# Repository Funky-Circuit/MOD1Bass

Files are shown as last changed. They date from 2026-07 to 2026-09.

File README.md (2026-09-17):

# MOD1Bass
Bass guitar inspired USB and BLE MIDI controller based on an Adafruit Feather ESP32-S3 board
(demo here: https://github.com/user-attachments/assets/1c9dc869-d182-4a1c-bf89-e89e9eab036d)

-- -- --

a bass model was designed for this project. you can find all the files needed in the "MOD1Bass_models" folder and print them or create you own model

-- -- --

all the code for this project was made using the Arduino IDE and the following libraries:
- MiniCore:
https://github.com/mcudude/minicore
- NimBLE:
https://github.com/h2zero/NimBLE-Arduino
- Arduino ESP32:
https://github.com/espressif/arduino-esp32
- Adafruit MAX1704X:
https://github.com/adafruit/Adafruit_MAX1704X
- Adafruit SSD1327:
https://github.com/adafruit/Adafruit_SSD1327
- Adafruit Seesaw:
https://github.com/adafruit/adafruit_seesaw

-- -- --

how to assemble this project:

1. you will need the PCB contained in the "PCB_MOD1Bass_B.json" file (that you can open in the software EasyEDA) with the bottom side preassembled. it will be refered as fretboard.

2. get 4 Atmega328p: for each of them, you will need to burn the bootloader and upload the file "MOD1Bass_fretboard.ino" into them. to do so, you will need an external programmer or an Arduino who is going to act as a programmer thanks to the Arduino IDE example "ArduinoISP". you will need to conect an external 16MHz clock to the Atmega328p and then burn the appropriate bootloader from the minicore board selection.

3. each time you upload the file "MOD1Bass_fretboard.ino" into an Atmega328p after the first, on line 17, you will need to modify the I2C address to 0x12 for the second, 0x13 for the third and 0x14 fo the fourth (for example "Wire.begin(0x12);" for the second) before uploading.

4. once all the Atmega328p are ready, put each of the in on of the four DIP socket on the fretboard (they have a specific order: from left to right, viewed from the top side: 0x11, 0x12, 013, 0x14).

5. connect the fretboard to the screen, the screen to the ANO controller and the ANO controller to the Adafruit Feather ESP32-S3 board with qwiic cables.

6. connect 4 force sensitive resistors (FSRs) to A0, A1, A2 and A3 of the Adafruit Feather ESP32-S3 board, with a 10k pulldown resistor on the signal each. starting from A0 on the left, dispose the FSRs next to each other in the order they where connected (A0, then A1, then A2 and to fnish A3). the other pin of the FSRs needs to be connected to one of the 3V pin of the Adafruit Feather ESP32-S3 board.

7. connect toggle switch (with one pin on the A4 pin and the other pin on the 3V pin) and a li-po battery to the Adafruit Feather ESP32-S3 board (there is a JST 2-PH port made specificaly for power input)

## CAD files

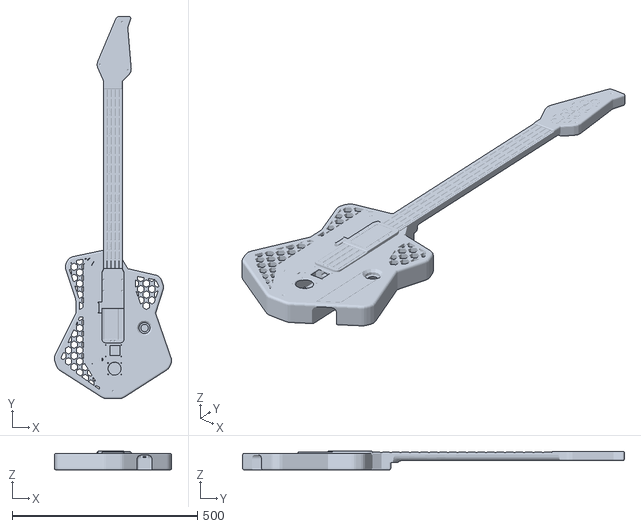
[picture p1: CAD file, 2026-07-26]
MOD1Bass_models/MOD1Bass_full.stl
316.7 x 1030.0 x 51.1

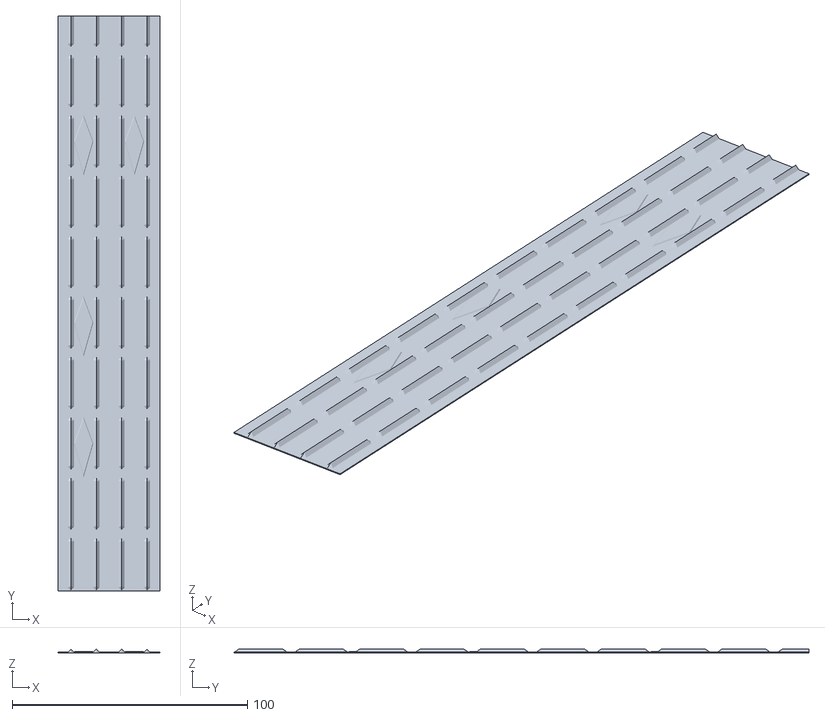
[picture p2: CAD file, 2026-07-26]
MOD1Bass_models/fretboard_topper_b.stl
43.2 x 244.3 x 1.59

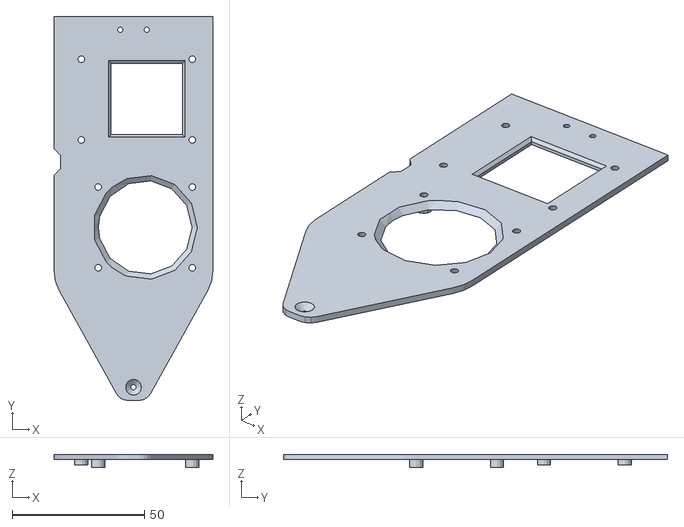
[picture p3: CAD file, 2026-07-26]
MOD1Bass_models/ano_screen_lid.stl
60.0 x 145.0 x 5.05

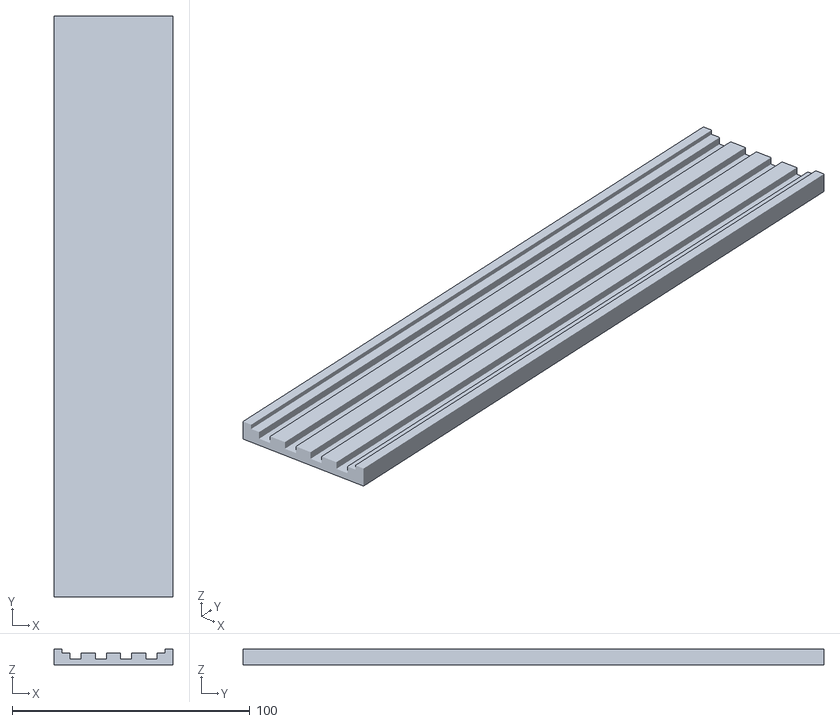
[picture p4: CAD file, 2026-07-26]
MOD1Bass_models/fretboard_holder_b.stl
50.0 x 244.3 x 6.60

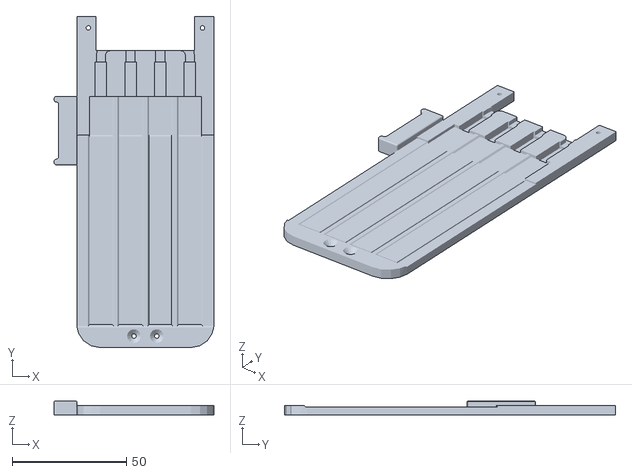
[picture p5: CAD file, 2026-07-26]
MOD1Bass_models/fsr_holder.stl
70.0 x 145.0 x 6.10

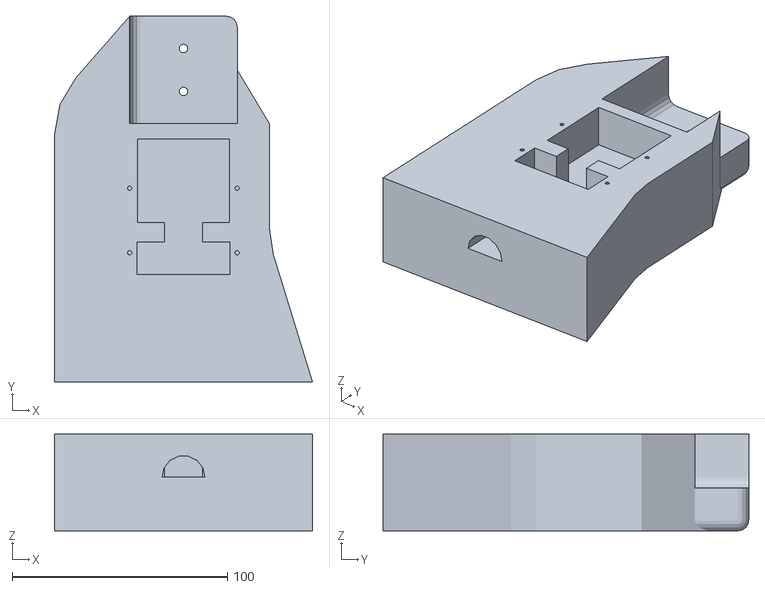
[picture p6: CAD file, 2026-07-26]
MOD1Bass_models/body_mid_t.stl
120.0 x 170.0 x 45.0

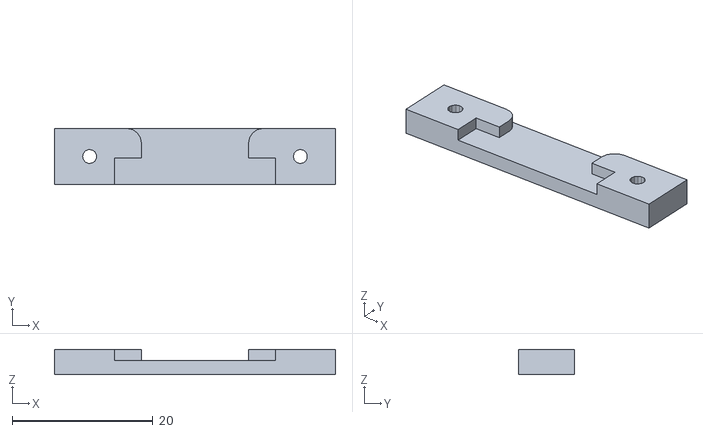
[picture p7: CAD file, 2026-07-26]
MOD1Bass_models/esp_holder.stl
40.0 x 8.01 x 3.59

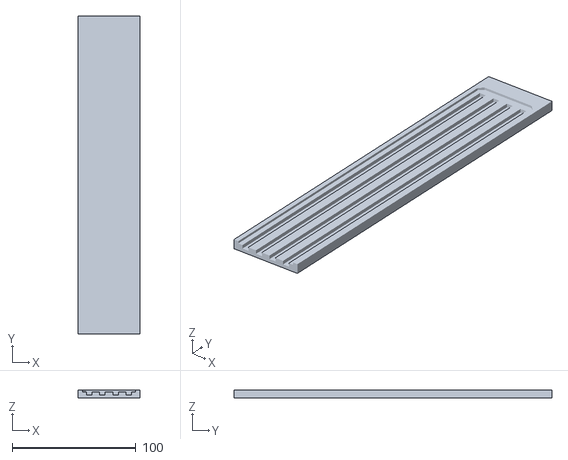
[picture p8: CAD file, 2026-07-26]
MOD1Bass_models/fretboard_holder_t.stl
50.0 x 257.2 x 6.60

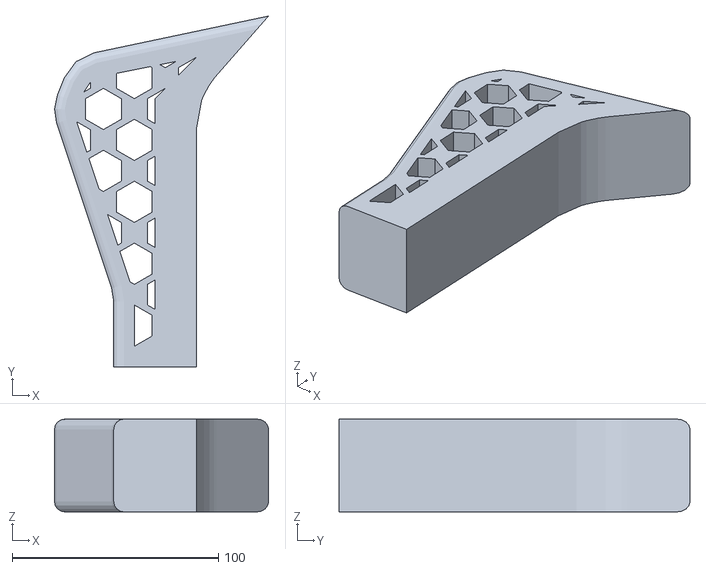
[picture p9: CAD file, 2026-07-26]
MOD1Bass_models/body_left_t.stl
103.7 x 170.0 x 45.0

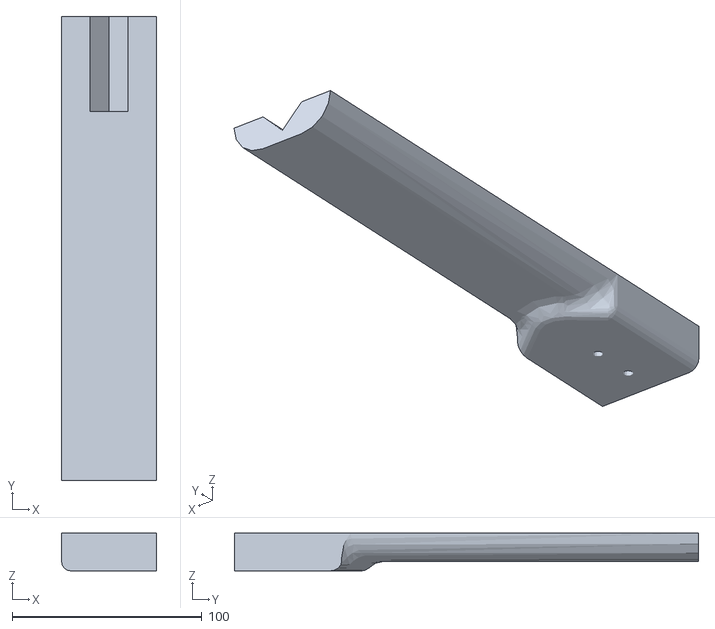
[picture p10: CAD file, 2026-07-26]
MOD1Bass_models/neck_b.stl
50.0 x 244.3 x 20.0

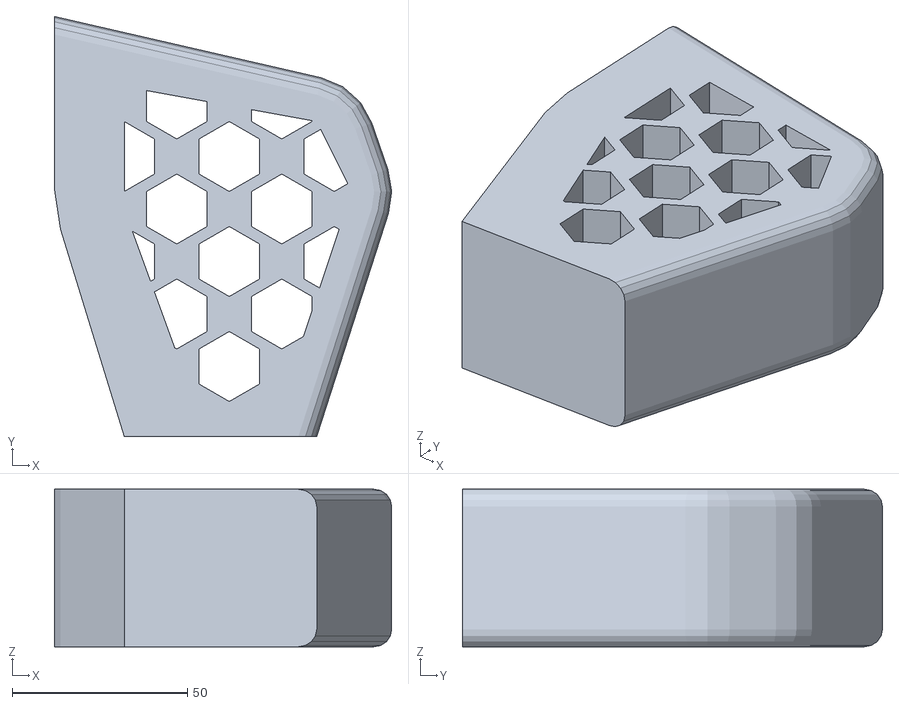
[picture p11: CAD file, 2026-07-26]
MOD1Bass_models/body_right_t.stl
96.4 x 120.0 x 45.0

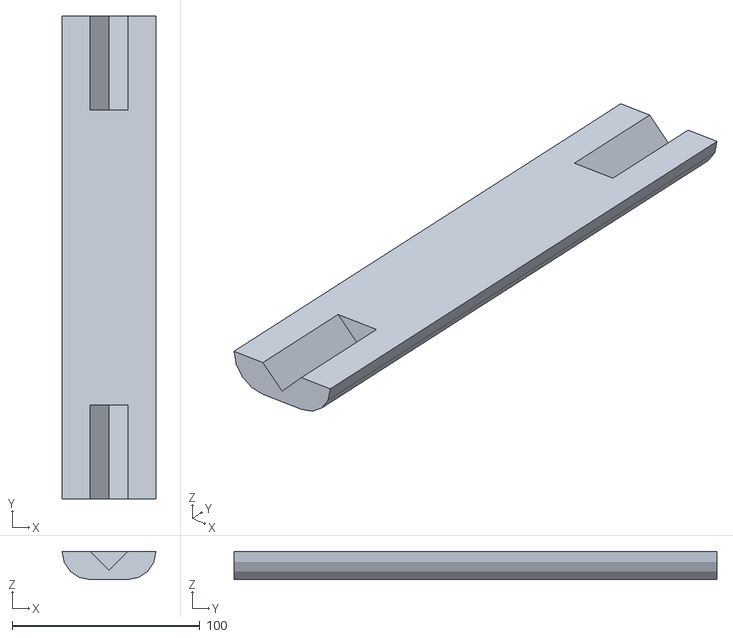
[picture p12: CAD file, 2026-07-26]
MOD1Bass_models/neck_t.stl
50.0 x 257.2 x 15.0

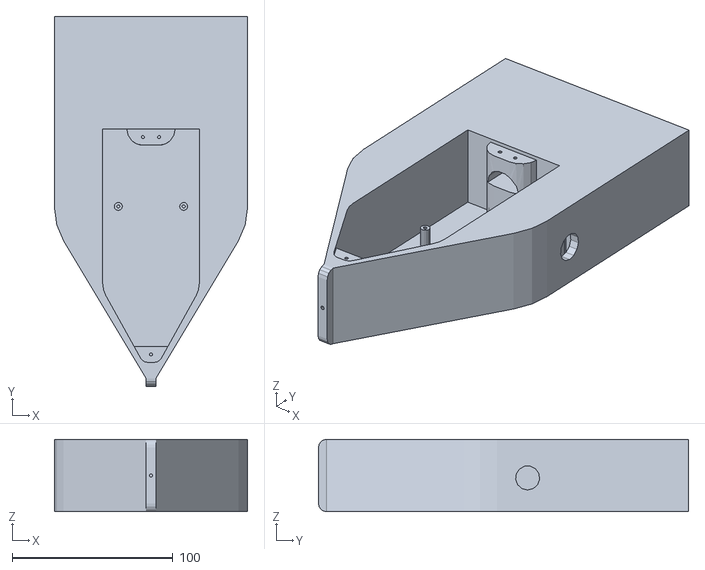
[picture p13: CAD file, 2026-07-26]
MOD1Bass_models/body_mid_b.stl
120.0 x 230.0 x 45.0

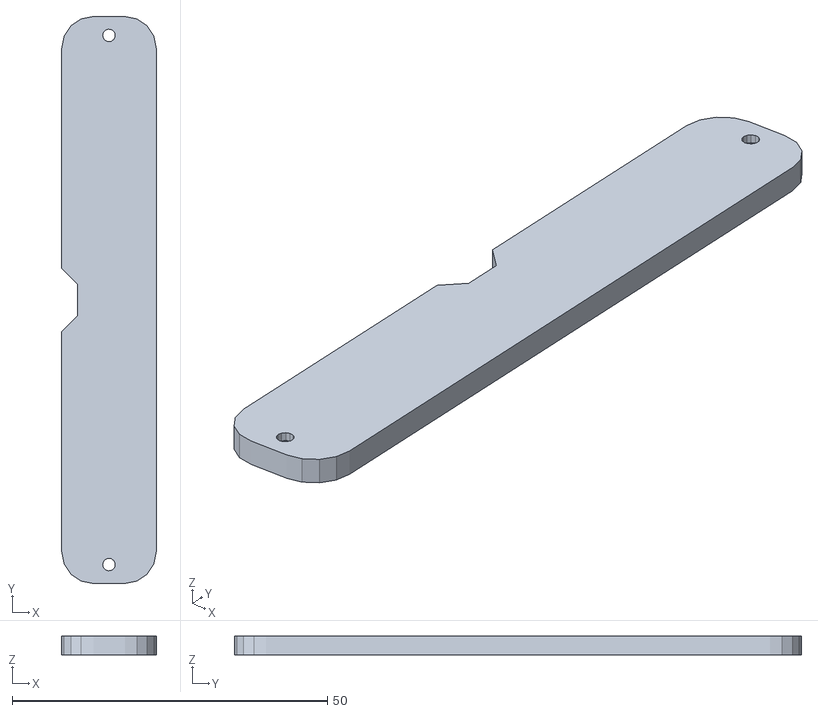
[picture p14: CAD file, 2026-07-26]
MOD1Bass_models/battery_lid.stl
15.0 x 90.0 x 3.00

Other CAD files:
MOD1Bass_models/fretboard_topper_t.stl
MOD1Bass_models/esp_lid.stl
MOD1Bass_models/body_right_b.stl
MOD1Bass_models/body_left_b.stl
MOD1Bass_models/head.stl
MOD1Bass_models/head_topper.stl
MOD1Bass_models/neck_link.stl
MOD1Bass_models/pcb_fsr_lid.stl

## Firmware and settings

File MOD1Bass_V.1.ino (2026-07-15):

#include <NimBLEDevice.h>

#include "USB.h"
#include "USBMIDI.h"

#include "esp_sleep.h"

#include "Adafruit_MAX1704X.h"

#include <Adafruit_SSD1327.h>

#include "Adafruit_seesaw.h"

#include <Wire.h>





// -- -- -- -- -- constants / objects / variables -- -- -- -- --





//BLE
#define MIDI_SERVICE_UUID        "03B80E5A-EDE8-4B33-A751-6CE34EC4C700"
#define MIDI_CHARACTERISTIC_UUID "7772E5DB-3868-4112-A1A9-F2669D106BF3"
//
NimBLECharacteristic* pCharacteristic;
//
class ServerCallbacks : public NimBLEServerCallbacks 
{
  void onConnect(NimBLEServer* pServer, ble_gap_conn_desc* desc)
  {
    pServer->updateConnParams(desc->conn_handle, 6, 6, 0, 60);
  }

  void onDisconnect(NimBLEServer* pServer) 
  {
    NimBLEDevice::startAdvertising();
  }
};
//
uint8_t BLE_data_buffer[80];
uint8_t BLE_buffer_index = 0;
uint8_t last_millis_read;


//USB
USBMIDI MIDI("MOD1Bass");


//Battery Monitor
uint8_t current_battery_level;
uint8_t last_battery_level;
//
Adafruit_MAX17048 maxlipo;


//Display
#define OLED_CLK 13
#define OLED_MOSI 11
#define OLED_RESET -1
//
Adafruit_SSD1327 display(128, 128, &Wire, OLED_RESET, 1000000);


//ANO encoder
#define SS_SWITCH_SELECT 1
#define SS_SWITCH_UP     2
#define SS_SWITCH_LEFT   3
#define SS_SWITCH_DOWN   4
#define SS_SWITCH_RIGHT  5
//
#define SEESAW_ADDR      0x49
//
uint8_t button_state[5];
uint8_t button_state_backup[5];
bool button_state_change_flag;
int encoder_values[2][4] = {{40, 45, 50, 55}, {0, 0, 0, 0}};
int encoder_values_backup;
int select_press_count;
int matrix_pos_x;
int matrix_pos_y;
//
Adafruit_seesaw ss;


//string simulation struct
uint8_t trigger_threshold = 50;
uint8_t attack_delay = 50;
//
struct simulated_string
{
  //IOs I2C variable
  uint8_t IOs_address;
  uint8_t IOs_base_value;
  uint8_t current_IOs_value;
  uint8_t last_IOs_value;
  //sensor analog variables
  uint8_t sensor_input_pin;
  uint8_t current_sensor_value;
  uint8_t last_sensor_value;
  bool trigger_flag;
  int trigger_timing;
  bool attack_flag;
  //MIDI channel variable
  uint8_t MIDI_channel;
};
//
simulated_string four_strings_bass[4];





// -- -- -- -- -- setup function -- -- -- -- --





void setup() {
  //Device init delay
  delay(5000);

  //BLE init
  NimBLEDevice::init("MOD1Bass");
  NimBLEDevice::setMTU(185);

  NimBLEServer* pServer = NimBLEDevice::createServer();
  pServer->setCallbacks(new ServerCallbacks());

  NimBLEService* pService = pServer->createService(MIDI_SERVICE_UUID);

  pCharacteristic = pService->createCharacteristic(
    MIDI_CHARACTERISTIC_UUID,
    NIMBLE_PROPERTY::READ |
    NIMBLE_PROPERTY::WRITE_NR |
    NIMBLE_PROPERTY::NOTIFY
  );

  pService->start();

  NimBLEAdvertising* pAdvertising = NimBLEDevice::getAdvertising();
  pAdvertising->addServiceUUID(MIDI_SERVICE_UUID);
  pAdvertising->start();

  //USB init
  MIDI.begin();
  USB.begin();

  //Battery Monitor init
  maxlipo.begin();

  //Display init
  display.begin(0x3D);
  display_settings();

  //ANO encoder init
  ss.begin(SEESAW_ADDR);

  ss.pinMode(SS_SWITCH_UP, INPUT_PULLUP);
  ss.pinMode(SS_SWITCH_DOWN, INPUT_PULLUP);
  ss.pinMode(SS_SWITCH_LEFT, INPUT_PULLUP);
  ss.pinMode(SS_SWITCH_RIGHT, INPUT_PULLUP);
  ss.pinMode(SS_SWITCH_SELECT, INPUT_PULLUP);

  ss.enableEncoderInterrupt();

  //Generic I2C communication init
  Wire.begin();

  //GPIO init
  pinMode(A4, INPUT_PULLDOWN);

  //string simulation init
  for(uint8_t i = 0; i < 4; i++)
  {
    four_strings_bass[i].IOs_address = 0x11 + i;
    four_strings_bass[i].IOs_base_value = encoder_values[0][i];
    four_strings_bass[i].sensor_input_pin = 18 - i;
    four_strings_bass[i].MIDI_channel = encoder_values[1][i];
  }
}





// -- -- -- -- -- custom functions -- -- -- -- --





//BLE MIDI functions
void BLE_MIDI_Note_On(uint8_t channel, uint8_t note, uint8_t velocity)
{
  uint16_t timestamp = millis() & 0x1FFF;
  uint8_t header = 0x80 | ((timestamp >> 7) & 0x3F);
  uint8_t timeLow = 0x80 | (timestamp & 0x7F);
  if(BLE_buffer_index == 0)
  {
    BLE_data_buffer[BLE_buffer_index] = header; BLE_buffer_index ++;
  }
  BLE_data_buffer[BLE_buffer_index] = timeLow; BLE_buffer_index ++;
  BLE_data_buffer[BLE_buffer_index] = 0x90 + channel; BLE_buffer_index ++;
  BLE_data_buffer[BLE_buffer_index] = note; BLE_buffer_index ++;
  BLE_data_buffer[BLE_buffer_index] = velocity; BLE_buffer_index ++;
}


void BLE_MIDI_Note_Off(uint8_t channel, uint8_t note, uint8_t velocity)
{
  uint16_t timestamp = millis() & 0x1FFF;
  uint8_t header = 0x80 | ((timestamp >> 7) & 0x3F);
  uint8_t timeLow = 0x80 | (timestamp & 0x7F);
  if(BLE_buffer_index == 0)
  {
    BLE_data_buffer[BLE_buffer_index] = header; BLE_buffer_index ++;
  }
  BLE_data_buffer[BLE_buffer_index] = timeLow; BLE_buffer_index ++;
  BLE_data_buffer[BLE_buffer_index] = 0x80 + channel; BLE_buffer_index ++;
  BLE_data_buffer[BLE_buffer_index] = note; BLE_buffer_index ++;
  BLE_data_buffer[BLE_buffer_index] = velocity; BLE_buffer_index ++;
}


void BLE_MIDI_Control_Change(uint8_t channel, uint8_t function, uint8_t value)
{
  uint16_t timestamp = millis() & 0x1FFF;
  uint8_t header = 0x80 | ((timestamp >> 7) & 0x3F);
  uint8_t timeLow = 0x80 | (timestamp & 0x7F);
  if(BLE_buffer_index == 0)
  {
    BLE_data_buffer[BLE_buffer_index] = header; BLE_buffer_index ++;
  }
  BLE_data_buffer[BLE_buffer_index] = timeLow; BLE_buffer_index ++;
  BLE_data_buffer[BLE_buffer_index] = 0xB0 + channel; BLE_buffer_index ++;
  BLE_data_buffer[BLE_buffer_index] = function; BLE_buffer_index ++;
  BLE_data_buffer[BLE_buffer_index] = value; BLE_buffer_index ++;
}


void BLE_MIDI_send_buffer()
{
  if(BLE_buffer_index > 0)
  {
    if(millis() - last_millis_read > 5)
    {
      pCharacteristic->setValue(BLE_data_buffer, BLE_buffer_index);
      pCharacteristic->notify();
      BLE_buffer_index = 0;
      last_millis_read = millis();
    }
  }
}


//selected mode MIDI fuctions
void Mode_Note_On(uint8_t mode, uint8_t channel, uint8_t note, uint8_t velocity)
{
  if(mode == 0)
  {
    MIDI.noteOn(note, velocity, channel);
  }
  else
  {
    BLE_MIDI_Note_On(channel, note, velocity);
  }
}


void Mode_Note_Off(uint8_t mode, uint8_t channel, uint8_t note, uint8_t velocity)
{
  if(mode == 0)
  {
    MIDI.noteOff(note, velocity, channel);
  }
  else
  {
    BLE_MIDI_Note_Off(channel, note, velocity);
  }
}


void Mode_Control_Change(uint8_t mode, uint8_t channel, uint8_t function, uint8_t value)
{
  if(mode == 0)
  {
    MIDI.controlChange(function, value, channel);
  }
  else
  {
    BLE_MIDI_Control_Change(channel, function, value);
  }
}


//power functions
void sleep_mode()
{
  if(digitalRead(A4) == 0)
  {
    NimBLEDevice::deinit(true);
    esp_sleep_enable_ext0_wakeup(GPIO_NUM_14, 1);
    esp_deep_sleep_start();
  }
}

void display_battery()
{
  last_battery_level = current_battery_level;
  current_battery_level = (uint8_t)maxlipo.cellPercent();
  if(current_battery_level != last_battery_level)
  {
    display_settings();
  }
}


//display fuction
void display_settings()
{
  //display settings
  display.clearDisplay();
  display.setTextSize(1);
  display.setTextWrap(false);
  display.setTextColor(SSD1327_WHITE);
  display.setCursor(0,0);
  //display device name and version
  display.print("MOD1Bass V-1.0");
  //spacing
  for(int i = 0; i < 3; i++)
  {
    display.println();
  }
  //display mode
  display.print("mode: ");
  if(select_press_count == 0)
  {
    display.print("USB");
  }
  else
  {
    display.print("BLE");
  }
  //spacing
  for(int i = 0; i < 3; i++)
  {
    display.println();
  }
  //display battery state
  display.print("Battery: ");
  display.print((uint8_t)maxlipo.cellPercent());
  display.print("%");
  //spacing
  for(int i = 0; i < 3; i++)
  {
    display.println();
  }
  //print controller strings names (base notes)
  display.println("/ - E - A - D - G  /");
  display.println();
  //display rows for transposition and channel setting for each strings
  for(int i = 0; i <= 1; i++)
  {
    display.print("/ ");
    for(int j = 0; j <= 3; j++)
    {
      if(i == matrix_pos_y && j == matrix_pos_x) 
      {
        display.print(">");
      }
      else 
      {
        display.print(" ");
      }
      if(encoder_values[i][j] < 16)
      {
        display.print(0);
      }
      display.print(encoder_values[i][j], HEX);
      display.print(" ");
    }
    display.println(" /");
    display.println();
  }
  display.display();
}


//ANO encoder settings control
void settings_control()
{
  //get button current and previous state
  for(int i = 1; i <= 5; i++)
  {
    button_state_backup[i] = button_state[i];
    button_state[i] = ss.digitalRead(i);
    if(button_state[i] != button_state_backup[i])
    {
      button_state_change_flag = 1;
    }
  }
  //select button pressed
  if(button_state[SS_SWITCH_SELECT] == 0 && button_state[SS_SWITCH_SELECT] != button_state_backup[SS_SWITCH_SELECT])
  {
    select_press_count += 1;
    if(select_press_count > 1) 
    {
      select_press_count = 0;
    }
    if(select_press_count == 1)
    {
      NimBLEAdvertising* pAdvertising = NimBLEDevice::getAdvertising();
      pAdvertising->addServiceUUID(MIDI_SERVICE_UUID);
      pAdvertising->start();
    }
  }
  //directinal buttons pressed
  if(button_state[SS_SWITCH_UP] == 0 && button_state[SS_SWITCH_UP] != button_state_backup[SS_SWITCH_UP])
  {
    matrix_pos_y += 1;
    if(matrix_pos_y > 1) 
    {
      matrix_pos_y = 0;
    }
  }
  if(button_state[SS_SWITCH_DOWN] == 0 && button_state[SS_SWITCH_DOWN] != button_state_backup[SS_SWITCH_DOWN])
  {
    matrix_pos_y -= 1;
    if(matrix_pos_y < 0) 
    {
      matrix_pos_y = 1;
    }
  }
  if(button_state[SS_SWITCH_RIGHT] == 0 && button_state[SS_SWITCH_RIGHT] != button_state_backup[SS_SWITCH_RIGHT])
  {
    matrix_pos_x += 1;
    if(matrix_pos_x > 3) 
    {
      matrix_pos_x = 0;
    }
  }
  if(button_state[SS_SWITCH_LEFT] == 0 && button_state[SS_SWITCH_LEFT] != button_state_backup[SS_SWITCH_LEFT])
  {
    matrix_pos_x -= 1;
    if(matrix_pos_x < 0) 
    {
      matrix_pos_x = 3;
    }
  }
  //encoder movement
  encoder_values_backup = encoder_values[matrix_pos_y][matrix_pos_x];
  encoder_values[matrix_pos_y][matrix_pos_x] += ss.getEncoderDelta();
  if(encoder_values[0][matrix_pos_x] > 108)
  {
    encoder_values[0][matrix_pos_x] = 21;
  }
  if(encoder_values[0][matrix_pos_x] < 21)
  {
    encoder_values[0][matrix_pos_x] = 108;
  }
  if(encoder_values[1][matrix_pos_x] > 15)
  {
    encoder_values[1][matrix_pos_x] = 0;
  }
  if(encoder_values[1][matrix_pos_x] < 0)
  {
    encoder_values[1][matrix_pos_x] = 15;
  }
  //check for setting value change and display it if needed
  if((button_state_change_flag == 1) || (encoder_values[matrix_pos_y][matrix_pos_x] != encoder_values_backup))
  {
    four_strings_bass[matrix_pos_x].IOs_base_value = encoder_values[0][matrix_pos_x];
    four_strings_bass[matrix_pos_x].MIDI_channel = encoder_values[1][matrix_pos_x];
    button_state_change_flag = 0;
    BLE_MIDI_Control_Change(0, 0x7B, 0);
    MIDI.controlChange(0x7B, 0, 0);
    display_settings();
  }
}


void string_simulator(simulated_string& string)
{
  //get wich fret is pressed and backup of wich was pressed last loop
  string.last_IOs_value = string.current_IOs_value;
  Wire.requestFrom(string.IOs_address, 1);
  while (Wire.available()) 
  {
    string.current_IOs_value = string.IOs_base_value + Wire.read();
  }

  //get pressure value on FSR and the backup value of the last loop
  string.last_sensor_value = string.current_sensor_value;
  string.current_sensor_value = constrain(map(analogRead(string.sensor_input_pin), 0, 4095, 0, 127), 0, 127);

  //trigger attack timer
  if(string.current_sensor_value > trigger_threshold && string.trigger_flag == 0)
  {
    string.trigger_timing = millis();
    string.trigger_flag = 1;
  }

  //note attack at timer ends
  if(((millis() - string.trigger_timing) > attack_delay) && (string.trigger_flag == 1) && (string.attack_flag == 0))
  {
    Mode_Note_On(select_press_count, string.MIDI_channel, string.current_IOs_value, string.current_sensor_value);
    string.attack_flag = 1;
  }

  //change note if a note is still playing
  if((string.current_IOs_value != string.last_IOs_value) && (string.attack_flag == 1))
  {
    Mode_Note_On(select_press_count, string.MIDI_channel, string.current_IOs_value, string.current_sensor_value);
    Mode_Note_Off(select_press_count, string.MIDI_channel, string.last_IOs_value, 0);
  }

  //release note
  if((string.current_sensor_value < trigger_threshold) && (string.attack_flag == 1))
  {
    Mode_Note_Off(select_press_count, string.MIDI_channel, string.current_IOs_value, 0);
    string.trigger_flag = 0;
    string.attack_flag = 0;
  }
}





// -- -- -- -- -- loop function -- -- -- -- --





void loop() 
{
  sleep_mode();
  display_battery();
  settings_control();
  for(uint8_t i = 0; i < 4; i++)
  {
    string_simulator(four_strings_bass[i]);
  }
  if(select_press_count == 1)
  {
    BLE_MIDI_send_buffer();
  }
}

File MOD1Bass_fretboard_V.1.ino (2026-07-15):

#include "Wire.h"



// -- -- -- -- --



void setup() 
{
  DDRB = 0;
  DDRC = 0;
  DDRD = 0;
  PORTB = 0;
  PORTC = 0;
  PORTD = 0;
  Wire.begin(0x11);
  Wire.onRequest(data_request);
}



// -- -- -- -- --



void loop() 
{

}



// -- -- -- -- --



void data_request()
{
  uint8_t array_size = 19;
  uint8_t IO_read[array_size] = 
  {
    (PIND & (1 << PD0)), (PINC & (1 << PC2)), (PIND & (1 << PD1)), (PINC & (1 << PC1)), (PIND & (1 << PD2)),
    (PINC & (1 << PC0)), (PIND & (1 << PD3)), (PINB & (1 << PB5)), (PIND & (1 << PD4)), (PINB & (1 << PB4)),
    (PINB & (1 << PB6)), (PINB & (1 << PB3)), (PINB & (1 << PB7)), (PINB & (1 << PB2)), (PIND & (1 << PD5)),
    (PINB & (1 << PB1)), (PIND & (1 << PD6)), (PINB & (1 << PB0)), (PIND & (1 << PD7))
  };
  uint8_t data = 0;
  for(int i = 0; i < sizeof(IO_read); i ++)
  {
    if(IO_read[i] > 0)
    {
      data = i + 1;
    }
  }
  Wire.write(data);
}

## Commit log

2026-07-15 Update README with project libraries and assembly steps
    Added assembly instructions and library references for the MOD1Bass project.
2026-07-15 Update assembly instructions in README
    Added detailed instructions for assembling the project, including component requirements and setup steps.
2026-07-15 Update README with PCB file details and instructions
    Clarified PCB file reference and added software context.
2026-07-26 add 3D files
    [MOD1Bass_full.stl, ano_screen_lid.stl, battery_lid.stl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]
